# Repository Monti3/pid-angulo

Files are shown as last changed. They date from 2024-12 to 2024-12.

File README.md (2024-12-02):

# Control PID de ángulo con potenciometro
> Empleando un puente H para controlar el motor DC con la pico y el potenciometro como retroalimentación, la Teoría de control nos permite acomodar el valor ADC asociado al potenciometro que a su vez esta asociado al motor para completar el lazo cerrado. 


 
## Integrantes

* Juan Cruz Isola
* Rodrigo Lin  
* Juan Ignacio Montilla
* Selene Ramirez 
* Santiago Alberto Zacarias

## 

[Página Web del proyecto](https://zacoso.github.io/)

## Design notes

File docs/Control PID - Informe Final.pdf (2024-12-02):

# Control PID de Angulo de Motor con Raspberry Pi ´ Pico

Santiago Zacar´ıas, Juan Montilla, Juan Isola, Rodrigo Lin, Selene Ramirez Escuela de Educacion T ´ ecnica N°7 ´ Email: {santiagozacarias, juanignaciomontilla, juancruzisola, rodrigoalexislin, selenenahirramirez}@impatrq.com

Abstract—Bajo la idea de hacer un control PID de angulo de ´ un motor DC, se emplea un potenciometro multivuelta y una raspebrry pi pico para la parte logica. ´

I. INTRODUCCION´

El control preciso de motores es fundamental en numerosas aplicaciones de la ingenier´ıa y la robotica. Este proyecto se ´ centra en el control del angulo de una aguja utilizando una ´ Raspberry Pi Pico, un motor DC y un conjunto de engranajes. El objetivo es demostrar la capacidad de la Raspberry Pi Pico para gestionar el movimiento de un motor mediante un sistema PID.

II. DESCRIPCION DEL ´ | PROYECTO

El sistema esta compuesto por un motor DC que acciona ´ un engranaje pequeno, el cual mueve un engranaje grande ˜ asociado a un potenciometro multivuelta. La Raspberry Pi Pico ´
interpreta las senales del potenci ˜ | ometro y ajusta el ´ | angulo de ´
la aguja mediante el control del motor.

III. COMPONENTES
- Raspberry Pi Pico
- Motor DC
- Engranaje grande
- Engranaje pequenoF ˜
- Potenciometro multivuelta ´
- Transistores
- Diodos
- Resistencias
- Borneras
- Placa PCB
- Cables varios

IV. DESCRIPCION´ FUNCIONAL

1) Potenciometro Retroalimentaci ´ | on´
El potenciometro mide la posici ´ | on actual del motor ( ´ | angulo, ´
etc.) y genera una senal anal ˜ | ogica proporcional a esta posici ´ | on. ´
Esta senal se env ˜ | ´ıa a la Raspberry Pi Pico como retroali-
mentacion para calcular el error (diferencia entre la posici ´ | | on´
deseada y la posicion actual). Raspberry Pi Pico (Controlador ´ PID):
La Raspberry Pi Pico recibe la senal del potenci ˜ | ometro y ´
la compara con el valor de referencia (setpoint), calculando el error. El controlador PID dentro de la Raspberry Pi procesa este error considerando tres componentes: Proporcional (P):
A. Diagrama de bloques

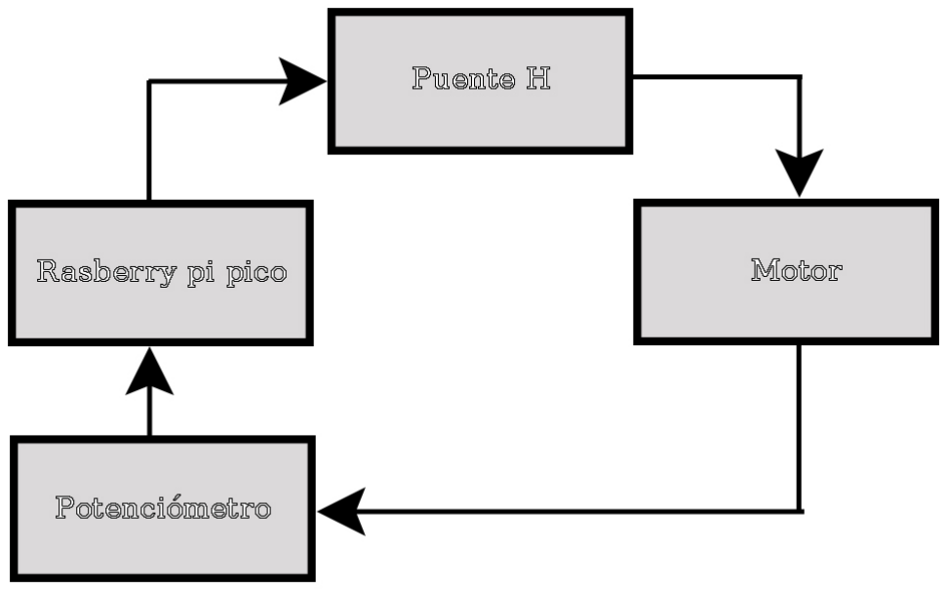
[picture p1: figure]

Fig. 1. Diagrama de bloques

Reacciona en proporcion directa al tama ´ | no del error, ajustando ˜
la salida para minimizarlo. Integral (I): Suma los errores a lo largo del tiempo para corregir desviaciones persistentes (errores acumulados). Derivativo (D): Analiza la tasa de cambio del error para anticipar y prevenir oscilaciones o sobreimpulsos. La salida del PID es una senal de control (por ˜ ejemplo, PWM) que regula el puente H. Puente H (Etapa de Potencia):

El puente H recibe la senal PWM generada por el contro- ˜ lador PID y la convierte en una senal de potencia adecuada ˜ para el motor. Permite controlar tanto la velocidad como el sentido de giro del motor, dependiendo de la magnitud y polaridad de la senal de entrada. Motor (Actuador): ˜

El motor ejecuta las ordenes recibidas del puente H, aju- ´
stando su posicion o velocidad seg ´ | un las indicaciones del ´
controlador. A medida que el motor se mueve, cambia la
lectura del potenciometro, cerrando as ´ | ´ı el lazo de control.
2) Ciclo de control PID:
El sistema esta dise ´ | nado para operar continuamente: La ˜
posicion actual del motor se mide mediante el potenci ´ | ometro. ´
El controlador PID procesa el error entre la posicion actual y la ´ referencia, ajustando la senal de salida al puente H. El puente ˜ H regula la potencia entregada al motor. El motor responde al ajuste, lo que a su vez actualiza la retroalimentacion medida ´ por el potenciometro. ´

B. Codigo y Circuito ´

Cuando el par de transistores PNP NPN opuestos (por ejemplo Q2 y Q4 en el esquematico) se activan permiten el ´ flujo de corriente de A a B y viceversa para el par opuesto (Q3 y Q1 en el esquematico). Si se activan los dos transistores ´ de una misma rama, se da un cortocircuito. El control de esos transistores de potencia lo podemos hacer asociando los pares de transistores PNP NPN opuestos mediante un transistor de
baja potencia. Es claro que bajo ningun concepto se deber ´ | an´
activar DIR1 y DIR2 al mismo tiempo ya que habr´ıa un cortocircuito en ambas ramas. Adicionalmente, podemos notar que es posible inyectar una senal pwm por una de las entradas ˜ DIR(ver el esquematico) mientras que la otra valga 0. De esta ´ manera, podemos variar la velocidad del motor.

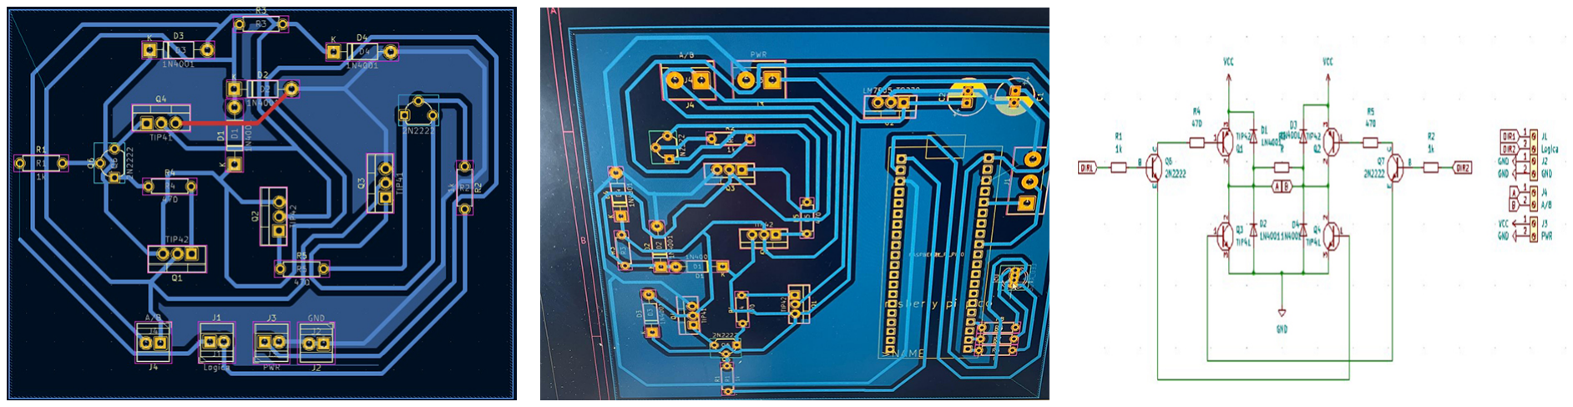
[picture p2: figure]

Fig. 2. Circuitos utilizados

V. ALCANCE LOGRADO

Aprendimos a implementar el control PID de una variable, ademas del diseno de un circuito de potencia como lo es un ˜ Puente H.

VI. CONCLUCIONES

La conclusion que sacamos es que no siempre todo sale ´ a la primera, y que siempre es conveniente probar y medir todo por separado, armado en protoboard y despues pasar al ´ circuito impreso.

VII. GALER´IA DE IMAGENES ´

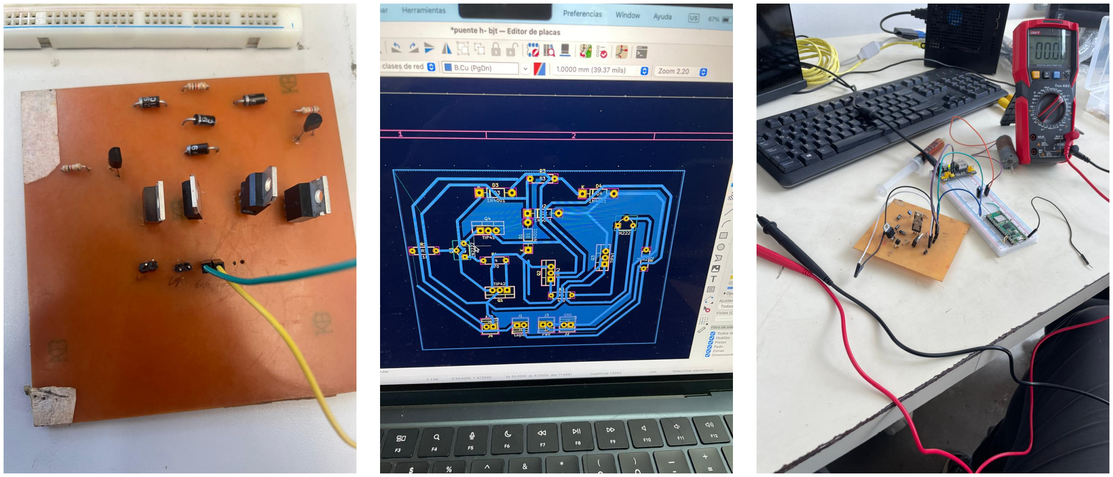
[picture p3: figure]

Fig. 3. Galer´ıa de Imagenes del Proyecto ´

VIII. VIDEO DEL PROYECTO

A continuacion, puedes ver el video del proyecto en ´ YouTube: Ver Aqu´ı. (https://www.youtube.com/watch?v=EmbxgZw8Rv4)

IX. DIVISION DE TAREAS ´

- Santiago Zacar´ıas
– Realizacion de informes t ´ | ecnicos ´
– Documentacion e investigaci ´ | on´
– Fabricacion de circuitos impresos ´
- Juan Montilla
– Diseno del c ˜ | odigo ´
– Ensayos estructurales y circuitales
- Juan Isola
– Diseno de carcasa y engranajes ˜
– Fabricacion de ruedas y circuito ´
- Rodrigo Lin
– Implementacion del hardware (ensamblaje) ´ – Ensayos estructurales y circuitales
– Control de calidad de los componentes
- Selene Ramirez
– Optimizacion de los componentes ´
– Puesta a punto

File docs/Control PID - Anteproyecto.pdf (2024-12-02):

### EEST N°7 - Computadoras y Sistemas de Control - Profesor Carlassara Fabrizio

## ANTEPROYECTO DE “S.A.T. (Sistema Autocontrolado de ”

### Integrante 1: Juan Isola juancruz.isola2209@gmail.com Integrante 2: Rodrigo Lin alexisrodrigolin@gmail.com Integrante 3: Montilla Juan montillajuanignacio@gmail.com Integrante 4: Santiago Zacarías sanfran120771@gmail.com Integrante 4: Selene Ramirez seleneramirez474@gmail.com

## 1. INTRODUCCIÓN

El proyecto consiste en un sistema de control de ángulo de un motor DC, posibilitando su uso en otras áreas.
Se hará con un control del tipo proporcional como mínimo. Intentaremos agregar la parte integral y derivativa, pero la prioridad es lo proporcional.

## 2. MARCO DE APLICACIÓN

El proyecto podría implementarse en la industria pesada, como brazos robóticos y otros dispositivos e incluso en prótesis en su control más fino.

## 3. DESCRIPCIÓN TÉCNICA

## 3.1 SOBRE EL HARDWARE

### 3.1.1 RASPBERRY PI PICO

Se planea usar como microcontrolador RP 2040 de la Raspberry Pi Pico. El motor a controlar será

### 3.1.2 Motor DC

Emplearemos motores de corriente continua para la demostración de la aplicación del control P.

### 3.1.3 Potenciómetro

Para completar el lazo cerrado de control, se usará un potenciómetro acoplado al eje a modo de encoder.

### 3.1.4 Puente H

Como etapa de potencia, desarrollaremos un puente H, compuesto por 4 transistores MOSFET, 2 transistores BJT, diodos de protección y resistencias . En el nodo común a los BC547 entra la señal PWM.

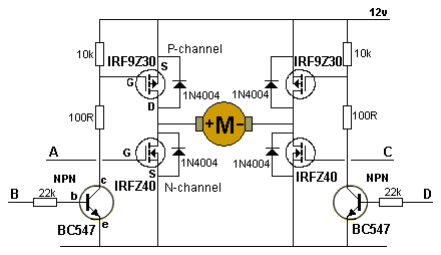
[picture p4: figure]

### 3.1.5 ESTRUCTURA

De soporte estructural se diseñarán e imprimirán piezas en 3D.

## 3.2 SOBRE EL SOFTWARE

Descripción de cuál es la estrategia para resolver el proyecto desde el punto de vista del software.
El principal objetivo es la implementación del control proporcional, por el software va a consistir principalmente de ese tipo de algoritmo.

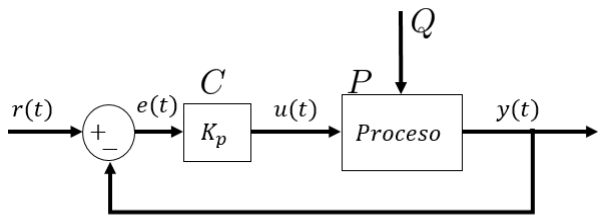
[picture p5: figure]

El ADC va a ser empleado para la lectura del potenciómetro, necesario para determinar el error

1

### EEST N°7 - Computadoras y Sistemas de Control - Profesor Carlassara Fabrizio

e(t). Un slice de un canal de PWM se usará para
entregar una salida variable, en orden de variar
porcentualmente el giro del motor, que de una entrada del puente H.

## 4. DIVISIÓN DE TAREAS

Detallar las tareas asignadas a cada integrante del equipo.

## 4.1 INTEGRANTE JUAN ISOLA

Software, desarrollo de la aplicación.

## 4.2 INTEGRANTE RODRIGO LIN

Hardware, armado y ensayo de circuitos.

## 4.3 INTEGRANTE JUAN MONTILLA

Software, desarrollo del firmware a emplear en el microcontrolador que usaremos. Modelado 3d

## 4.4 INTEGRANTE SANTIAGO ZACARÍAS

Hardware, implementación de las etapas de potencia y diseño de circuito.

## 4.4 INTEGRANTE SELENE RAMIREZ

Supervisión Técnica del proyecto y análisis de costos.

## 5. LISTA DE MATERIALES

Proporcionar una lista de materiales que se espera usar para el proyecto.

MATERIAL | COSTO (AR$)
Raspberry Pi Pico | 10000
Potenciómetros y Resistencias | 2100
4x MOSFET | 6000
2x BJT | 1000
4x Diodos | 400
Motor DC | ~5000(Reciclado)
Filamento, cables, etc. | ~5000

## 5. REFERENCIAS

Agregar cualquier referencia que se haya usado durante la investigación o el informe.

[1] Gemini 1. Disponible en: Gemini (https://gemini.google.com/app)
[2] Starware. Disponible en: Starware. (https://tienda.starware.com.ar/?s=potenciometro&post_type=product&dgwt_wcas=1)
[

2

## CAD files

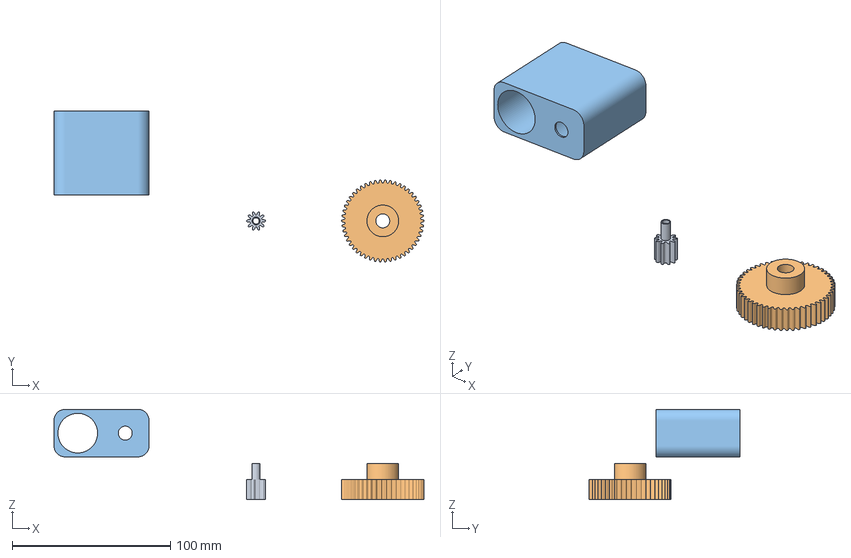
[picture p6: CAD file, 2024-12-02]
mechanical/Stand motor pid con engranajes.3mf
233.6 x 95.4 x 57.0 mm
(Sin guardar).stl 2
(Sin guardar).stl 3
(Sin guardar).stl 6

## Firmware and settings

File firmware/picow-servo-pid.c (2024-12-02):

#include <stdio.h>
#include "pico/stdlib.h"
#include "hardware/gpio.h"
#include "hardware/adc.h"
#include "hardware/pwm.h"

#define IN1 14
#define IN2 15
#define ADC_PIN 27

void start_pwm(uint8_t pin);
void set_pwm(uint8_t pin, float percentage);

int main()
{
    stdio_init_all();
    adc_init();
    adc_gpio_init(ADC_PIN);
    adc_select_input(1);

    start_pwm(IN1);
    start_pwm(IN2);

    float K_p = 3;

    uint16_t full_duty = 50000; // Wrap del PWM
    float desired_angle = 1000;
    float previous_error = 0; // Error del ciclo anterior
    float dt = 0.1f;
    float integral_error;
    float K_i = 0.01;
    float K_d = 1;
    uint16_t adc;

    while (true)
    {
        adc = adc_read();
        float error = (float)(desired_angle - adc);
        float derivative = (error - previous_error) / dt;
        float control_signal = (K_p * error) + (K_i * integral_error) + (K_d * derivative);
        integral_error += error * dt;
        if (integral_error > full_duty)
            integral_error = full_duty;
        if (integral_error < -full_duty)
            integral_error = -full_duty;

        if (integral_error > full_duty)
            integral_error = full_duty;
        if (integral_error < -full_duty)
            integral_error = -full_duty;

        if (error < 500 && error > -500)
        {
            control_signal = 0;
        }
        else
        {
            // Saturación del control_signal
            if (control_signal > full_duty)
                control_signal = full_duty;
            else if (control_signal < -full_duty)
                control_signal = -full_duty;
        }

        pwm_set_gpio_level(IN1, (control_signal > 0) ? (uint16_t)control_signal : 0);
        pwm_set_gpio_level(IN2, (control_signal < 0) ? (uint16_t)(-control_signal) : 0);

        printf("Error:%.2f\t Setpoint:%.2f\t ADC:%u\t ContolS:%.2f\n", error, desired_angle, adc, control_signal);

        sleep_ms(10);
    }
}

void start_pwm(uint8_t pin)
{
    gpio_set_function(pin, GPIO_FUNC_PWM);
    uint8_t slice = pwm_gpio_to_slice_num(pin);
    pwm_config config = pwm_get_default_config();
    pwm_config_set_clkdiv(&config, 50.0f); // Divisor = 50
    pwm_config_set_wrap(&config, 50000);   // Wrap = 50000
    pwm_init(slice, &config, true);
    pwm_set_gpio_level(pin, 0);
}

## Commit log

2024-12-02 primer commit
    [Stand motor pid con engranajes.3mf]
2024-12-02 cambio el nombre de Control PID - Infotme Final.pdf a Control PID - Informe Final.pdf
